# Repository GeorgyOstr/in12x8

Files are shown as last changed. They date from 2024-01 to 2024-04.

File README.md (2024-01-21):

# Yet another nixie display RTC project.

### Overview
Wanted to desing esp32 powered control board usable for multiple different 8 tubes clock.
Want to make 3 iterations of clocks.

Will try to code in platformio.

Case: glass lid, 3d print support, metal exterior.
Single Type-C connector.

Based on Tom Titor design.

### Target for v1
PCB design in EAGLE. Fusion for case.
All caps MLCC.

1. Display board 
    * 2 layers
    * Minimal footprint
    * SMD only
    * Circuitry on one side (tubes on opposite)
    * HV path minimized
    * 8 tubes IN12
    * [HV552](https://ww1.microchip.com/downloads/en/DeviceDoc/HV5523-32-Channel-Serial-to-Parallel-Converter-with-Open-Drain-Outputs-Data-Sheet-20005700A.pdf)
    
    * optional: custom HV supply onboard
    
2. Control board (beta)
    * 2 layers
    * Modules usage
    * Same footprint as display
    * Circuitry on one side
    * ESP32
    * [DS3232](https://www.analog.com/media/en/technical-documentation/data-sheets/ds3232.pdf)
    * [Taylor Electronics HVPS 1364](https://www.shop-tes.com/content/Datasheets/8002K.pdf)
    * [Potentiometer](https://www.mouser.jp/datasheet/2/609/MAX5460_MAX5468-3129691.pdf)
    * [Type C](https://www.mouser.jp/ProductDetail/Wurth-Elektronik/632723300021?qs=t3bE0qb%2FqEJYzZ4bEQN6Ug%3D%3D)
    * Full control on HV 

    * optional: battery support

### Target for v2

2. Control board
    * 2 layers
    * Minimal footprint
    * SMD only except USB-c
    * No modules
    * Battery support

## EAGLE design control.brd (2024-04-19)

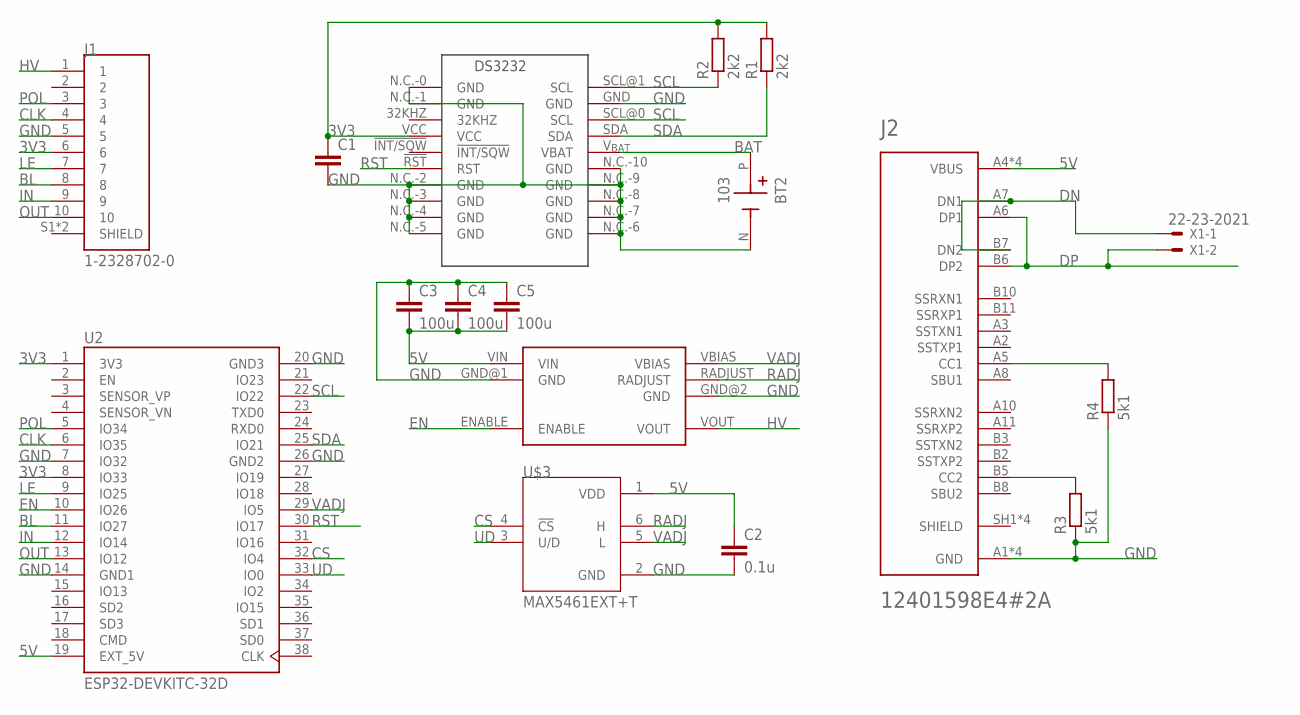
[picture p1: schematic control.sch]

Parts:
BT2: 103; BAT_103
C1: C-EUC0805; C0805
C2: 0.1u; C0805
C3, C4, C5: 100u; C1210
J1: 1-2328702-0; TE_1-2328702-0
J2: 12401598E4#2A; AMPHENOL_12401598E4#2A
R1, R2: 2k2; R0805
R3, R4: 5k1; R0805
U2: ESP32-DEVKITC-32D; MODULE_ESP32-DEVKITC-32D
U$1: DS3232; SO20-2
U$2: HV_PSU
U$3: MAX5461EXT+T; SOT65P210X110-6N
X1: 22-23-2021

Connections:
3V3: C1.1, J1.6, R1.2, R2.2, U2.1 (3V3), U2.8 (IO33), U$1.VCC
5V: C2.1, C3.2, C4.2, C5.2, J2.A4 (VBUS), J2.A9 (VBUS), J2.B4 (VBUS), J2.B9 (VBUS), U2.19 (EXT_5V), U$2.VIN, U$3.1 (VDD)
BAT: BT2.P (POS), U$1.V_{BAT} (VBAT)
BL: J1.8, U2.11 (IO27)
CLK: J1.4, U2.6 (IO35)
CS: U2.32 (IO4), U$3.4 (!CS)
DN: J2.A7 (DN1), J2.B7 (DN2), X1.1
DP: J2.A6 (DP1), J2.B6 (DP2), X1.2
EN: U2.10 (IO26), U$2.ENABLE
GND: BT2.N (NEG), C1.2, C2.2, C3.1, C4.1, C5.1, J1.5, J2.A1 (GND), J2.A12 (GND), J2.B1 (GND), J2.B12 (GND), R3.1, R4.1, U2.7 (IO32), U2.14 (GND1), U2.20 (GND3), U2.26 (GND2), U$1.GND, U$1.N.C.-0 (GND), U$1.N.C.-1 (GND), U$1.N.C.-2 (GND), U$1.N.C.-3 (GND), U$1.N.C.-4 (GND), U$1.N.C.-5 (GND), U$1.N.C.-6 (GND), U$1.N.C.-7 (GND), U$1.N.C.-8 (GND), U$1.N.C.-9 (GND), U$1.N.C.-10 (GND), U$2.GND@1 (GND), U$2.GND@2 (GND), U$3.2 (GND)
HV: J1.1, U$2.VOUT
IN: J1.9, U2.12 (IO14)
LE: J1.7, U2.9 (IO25)
unnamed: J2.B5 (CC2), R3.2
unnamed: J2.A5 (CC1), R4.2
OUT: J1.10, U2.13 (IO12)
POL: J1.3, U2.5 (IO34)
RADJ: U$2.RADJUST, U$3.6 (H)
RST: U2.30 (IO17), U$1.!RST (RST)
SCL: R2.1, U2.22 (IO22), U$1.SCL@0 (SCL), U$1.SCL@1 (SCL)
SDA: R1.1, U2.25 (IO21), U$1.SDA
SHIELD: J2.SH1 (SHIELD), J2.SH2 (SHIELD), J2.SH3 (SHIELD), J2.SH4 (SHIELD)
UD: U2.33 (IO0), U$3.3 (U/D)
VADJ: U2.29 (IO5), U$2.VBIAS, U$3.5 (L)

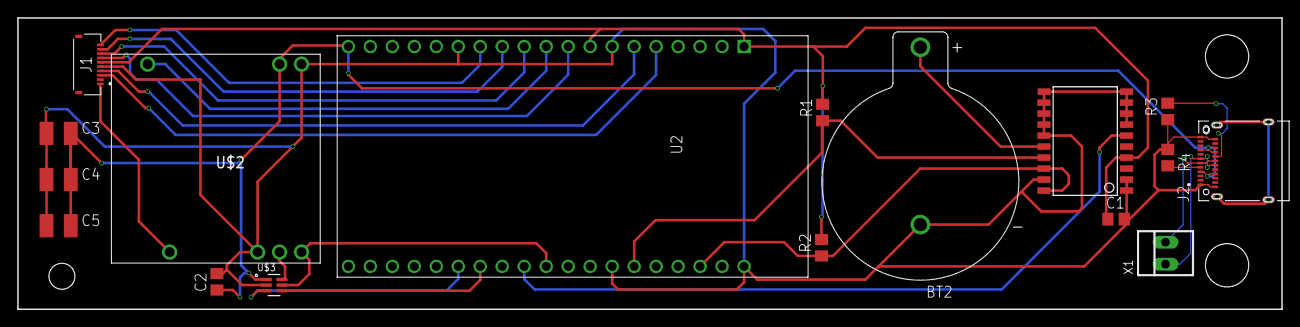
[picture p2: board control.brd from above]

Board: 2 copper layers, 146.1 x 33.7 mm, 17 parts (0 on the bottom side), 24 nets.

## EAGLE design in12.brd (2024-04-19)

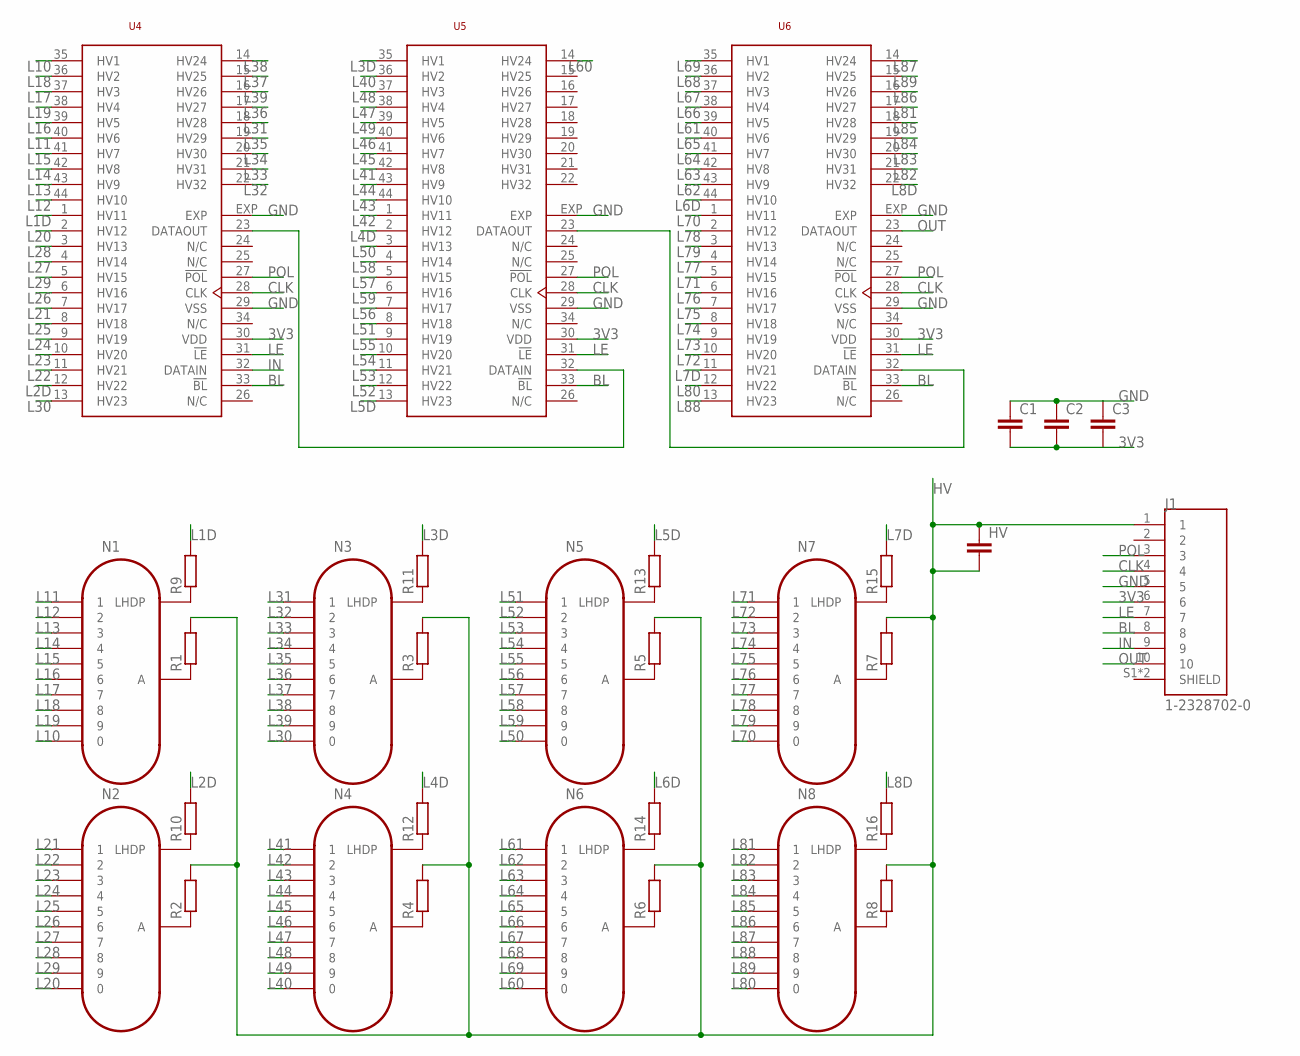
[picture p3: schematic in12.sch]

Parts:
C1, C2, C3: C-EUC0805; C0805
HV: C-EUC1206; C1206
J1: 1-2328702-0; TE_1-2328702-0
N1, N2, N3, N4, N5, N6, N7, N8: IN-12B; IN-12
R1, R2, R3, R4, R5, R6, R7, R8: R-EU_R1206; R1206
R9, R10, R11, R12, R13, R14, R15, R16: R-EU_R0805; R0805
U4, U5, U6: HV5523; QFN-44-7X7

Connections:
3V3: C1.2, C2.2, C3.2, J1.6, U4.30 (VDD), U5.30 (VDD), U6.30 (VDD)
BL: J1.8, U4.33 (!BL), U5.33 (!BL), U6.33 (!BL)
CLK: J1.4, U4.28 (CLK), U5.28 (CLK), U6.28 (CLK)
GND: C1.1, C2.1, C3.1, J1.5, U4.29 (VSS), U4.EXP, U5.29 (VSS), U5.EXP, U6.29 (VSS), U6.EXP
HV: HV.1, HV.2, J1.1, R1.2, R2.2, R3.2, R4.2, R5.2, R6.2, R7.2, R8.2
IN: J1.9, U4.32 (DATAIN)
L1D: R9.2, U4.1 (HV11)
L2D: R10.2, U4.12 (HV22)
L3D: R11.2, U5.35 (HV1)
L4D: R12.2, U5.2 (HV12)
L5D: R13.2, U5.13 (HV23)
L6D: R14.2, U6.44 (HV10)
L7D: R15.2, U6.11 (HV21)
L8D: R16.2, U6.22 (HV32)
L10: N1.0, U4.35 (HV1)
L11: N1.1, U4.40 (HV6)
L12: N1.2, U4.44 (HV10)
L13: N1.3, U4.43 (HV9)
L14: N1.4, U4.42 (HV8)
L15: N1.5, U4.41 (HV7)
L16: N1.6, U4.39 (HV5)
L17: N1.7, U4.37 (HV3)
L18: N1.8, U4.36 (HV2)
L19: N1.9, U4.38 (HV4)
L20: N2.0, U4.2 (HV12)
L21: N2.1, U4.7 (HV17)
L22: N2.2, U4.11 (HV21)
L23: N2.3, U4.10 (HV20)
L24: N2.4, U4.9 (HV19)
L25: N2.5, U4.8 (HV18)
L26: N2.6, U4.6 (HV16)
L27: N2.7, U4.4 (HV14)
L28: N2.8, U4.3 (HV13)
L29: N2.9, U4.5 (HV15)
L30: N3.0, U4.13 (HV23)
L31: N3.1, U4.18 (HV28)
L32: N3.2, U4.22 (HV32)
L33: N3.3, U4.21 (HV31)
L34: N3.4, U4.20 (HV30)
L35: N3.5, U4.19 (HV29)
L36: N3.6, U4.17 (HV27)
L37: N3.7, U4.15 (HV25)
L38: N3.8, U4.14 (HV24)
L39: N3.9, U4.16 (HV26)
L40: N4.0, U5.36 (HV2)
L41: N4.1, U5.42 (HV8)
L42: N4.2, U5.1 (HV11)
L43: N4.3, U5.44 (HV10)
L44: N4.4, U5.43 (HV9)
L45: N4.5, U5.41 (HV7)
L46: N4.6, U5.40 (HV6)
L47: N4.7, U5.38 (HV4)
L48: N4.8, U5.37 (HV3)
L49: N4.9, U5.39 (HV5)
L50: N5.0, U5.3 (HV13)
L51: N5.1, U5.8 (HV18)
L52: N5.2, U5.12 (HV22)
L53: N5.3, U5.11 (HV21)
L54: N5.4, U5.10 (HV20)
L55: N5.5, U5.9 (HV19)
L56: N5.6, U5.7 (HV17)
L57: N5.7, U5.5 (HV15)
L58: N5.8, U5.4 (HV14)
L59: N5.9, U5.6 (HV16)
L60: N6.0, U5.14 (HV24)
L61: N6.1, U6.39 (HV5)
L62: N6.2, U6.43 (HV9)
L63: N6.3, U6.42 (HV8)
L64: N6.4, U6.41 (HV7)
L65: N6.5, U6.40 (HV6)
L66: N6.6, U6.38 (HV4)
L67: N6.7, U6.37 (HV3)
L68: N6.8, U6.36 (HV2)
L69: N6.9, U6.35 (HV1)
L70: N7.0, U6.1 (HV11)
L71: N7.1, U6.5 (HV15)
L72: N7.2, U6.10 (HV20)
L73: N7.3, U6.9 (HV19)
L74: N7.4, U6.8 (HV18)
L75: N7.5, U6.7 (HV17)
L76: N7.6, U6.6 (HV16)
L77: N7.7, U6.4 (HV14)
L78: N7.8, U6.2 (HV12)
L79: N7.9, U6.3 (HV13)
L80: N8.0, U6.12 (HV22)
L81: N8.1, U6.17 (HV27)
L82: N8.2, U6.21 (HV31)
L83: N8.3, U6.20 (HV30)
L84: N8.4, U6.19 (HV29)
L85: N8.5, U6.18 (HV28)
L86: N8.6, U6.16 (HV26)
L87: N8.7, U6.14 (HV24)
L88: N8.8, U6.13 (HV23)
L89: N8.9, U6.15 (HV25)
LE: J1.7, U4.31 (!LE), U5.31 (!LE), U6.31 (!LE)
unnamed: N1.A, R1.1
unnamed: N2.A, R2.1
unnamed: N3.A, R3.1
unnamed: N4.A, R4.1
unnamed: N5.A, R5.1
unnamed: N6.A, R6.1
unnamed: N7.A, R7.1
unnamed: N8.A, R8.1
unnamed: N1.LHDP, R9.1
unnamed: N2.LHDP, R10.1
unnamed: N3.LHDP, R11.1
unnamed: N4.LHDP, R12.1
unnamed: N5.LHDP, R13.1
unnamed: N6.LHDP, R14.1
unnamed: N7.LHDP, R15.1
unnamed: N8.LHDP, R16.1
unnamed: U4.23 (DATAOUT), U5.32 (DATAIN)
unnamed: U5.23 (DATAOUT), U6.32 (DATAIN)
OUT: J1.10, U6.23 (DATAOUT)
POL: J1.3, U4.27 (!POL), U5.27 (!POL), U6.27 (!POL)

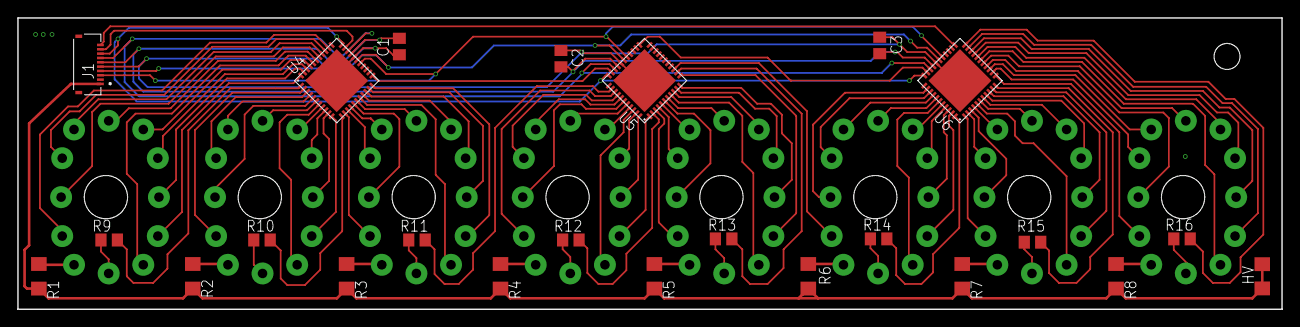
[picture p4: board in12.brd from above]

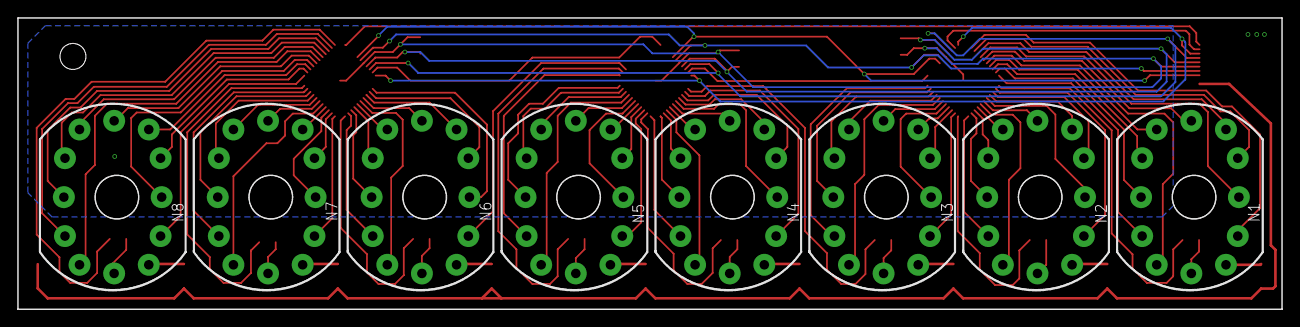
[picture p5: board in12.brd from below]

Board: 2 copper layers, 146.1 x 33.7 mm, 32 parts (8 on the bottom side), 115 nets.

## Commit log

2024-01-10 5523 still need shuffle pins
    [in12.brd, in12.sch]
2024-01-12 hv single layer routed
    [in12.brd, in12.sch]
2024-01-12 added m.2 connector
    [in12.brd, in12.sch]
2024-01-14 control board, adapter ffc wire
    [control.brd, control.sch, in12.brd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]
2024-01-15 routing connector
    [in12.brd, in12.sch]
2024-01-15 lamp board finished, working on control
    [control.brd, control.sch, in12.brd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]
2024-01-20 add readme, brushup board
    [control.brd, control.sch, in12.brd]
2024-01-20 added potentio, readme update
    [control.brd, control.sch]
2024-01-21 reg update
    [control.brd, control.sch]
2024-01-21 Found wurth typec
    [control.brd, control.sch]
2024-04-19 started ratsnest, finished usb-c viring
    [control.brd, control.sch, in12.brd]
